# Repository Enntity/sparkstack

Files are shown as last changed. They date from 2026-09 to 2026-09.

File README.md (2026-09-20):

# SparkStack

A stackable, modular, 3D-printable rack for the NVIDIA DGX Spark. One to four
machines in a 205 mm footprint.

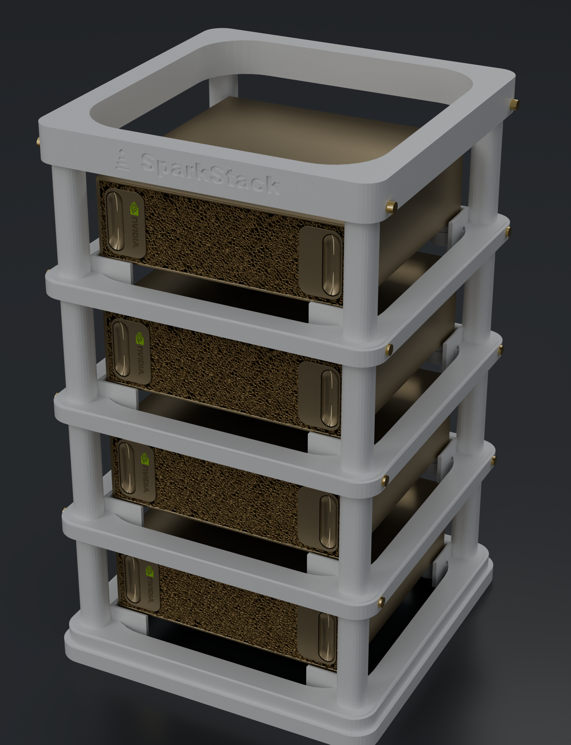
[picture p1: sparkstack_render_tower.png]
SparkStack, four machines high


Printed in ABS or ASA. Every part fits a 220 × 220 mm bed.

**Status: built and in use.** Two machines sit in a prototype on a desk, and the
assembly is fine to live with. The three structural parts are published below;
the decorative panels are not yet.

**Not affiliated with, endorsed by, or sponsored by NVIDIA.** "DGX" and "Spark"
are trademarks of NVIDIA Corporation. This is an independent accessory.

## What's here

| | |
|---|---|
| `stl/` | Ready-to-slice STLs for v3.0 |
| `sparkstack.py` | Structure generator — base, tiers, cap |
| `sparkstack_panels.py` | Decorative panel generator |
| `render_sparkstack.py` | Renders: white rack, real Sparks, gold pins |
| `render_hive.py` | Renders: dark organic finish, panels on |
| `render.sh` | Blender wrapper (see *Renders*) |
| `validate_stl.py` | Checks exports are closed, watertight, single-shell |
| `profiles/` | OrcaSlicer profiles for ASA on a FlashForge AD5M Pro |

## Print set

| File | Qty |
|---|---|
| `sparkstack_v3_0_base.stl` | 1 |
| `sparkstack_v3_0_tier.stl` | 1 per machine |
| `sparkstack_v3_0_cap.stl` | 1 |
| `sparkstack_v3_0_tier_pinned.stl` | optional — the tier with the pin bore opened through the rail. **See The joint** |

**Three parts.** A four-machine stack is one base, four tiers, one cap. The
`tier_pinned` file is the same tier with one bore opened up; print it instead of
`tier` if you want to use pins.

The **decorative panels are not in this release.** The generator is here and the
renders below show them fitted, but the panel STLs are not published yet — see
*Panels* for how they work and why they need a little more time.

## Model

1 unit = 1 mm. Everything is generated, not hand-modelled:

```bash
blender --background --python sparkstack.py    # writes stl/ and a spec sheet
```

Key parameters live in the `P` dict at the top of `sparkstack.py`:

| | | |
|---|---|---|
| `PITCH` | 76 mm | tier spacing; sets the air gap above each machine |
| `DEV_W` / `DEV_D` / `DEV_H` | 150 / 150 / 51.2 | the machine |
| `SIDE_CLEAR` | 1.5 mm | post clearance |
| `JOINT_CLR` | 0.15 mm | bore clearance; the ribs interfere by 0.10 mm/side |
| `RAIL_PROUD` | 2.0 mm | panel rail standoff |
| `CRADLE_CLR` | 1.0 mm | corner cradle clearance, sized for ASA shrinkage |
| `BASE_R` | 14 mm | base corner radius |

## The constraint that shapes everything

The machine draws air in through its **front face** (upper and lower) and its
**underside**, both dust-filtered, and exhausts out the **rear** heatsink fins
and the QSFP fin stack.
([ChargerLAB teardown](https://www.chargerlab.com/teardown-of-nvidia-dgx-spark-4tb/))

So there is no shelf under it. The tier ring opens to **168 × 168 mm**, wider
than the machine's own 150 mm silhouette, leaving a 9 mm annulus around the
chassis. The machine rests on **four Ø14 mm pads** at (±68, ±68) mm, shadowing
**3.5% of the underside**, all at the corners.

That is also why the panels are **open webbing rather than solid skins** — a
closed front panel would strangle the intake.

`PITCH` sets the air gap above each machine: at 76 mm it is **11.8 mm**. For
scale, buoyancy across a full four-tier stack is ~0.26 Pa against tens of Pa
from the machine's own blowers, and the intake annulus costs ~0.13–0.25 Pa at a
plausible 10–20 CFM. The rack's contribution to the intake path is small, and
the gap above the machine is not in that path at all: the top of the chassis is
neither intake nor exhaust.

**The mechanical design is built and in use.** Two machines sit in a prototype
on a desk — they locate in the cradles, the tiers stack and hold, and the
assembly has been fine to live with.

**The numbers on this page are not the reason for that.** Every figure above is
analysis from published specs and first principles — buoyancy, annulus pressure
drop, the rising gap. No temperature logging has been done under sustained
load, and the machine dimension used throughout is the published spec, not a
measurement of the unit on the desk. Take the numbers as the reasoning behind
the shape, not as verification of it.

## Panels

**Not shipped yet.** The renders at the top of this README show them fitted;
the STLs are not in this release. Everything below describes the design as
built, so the generator in `sparkstack_panels.py` and the geometry it produces
match what you see — but treat the panel files as unreleased until they appear
in `stl/`.

Each tier's front comes from its own seed, so a stack doesn't read as four
copies of one part. The sides are identical across tiers.

The panels are flat 4 mm plates with a hook along the bottom of the inner face
that drops over a rail on the tier. Printed flat, the panel's inner face is up,
so the hook is a step in the top surface — there is no overhang anywhere, which
matters because ABS and ASA with near-zero part cooling will string and stay
uncured on any unsupported ceiling.

An earlier attempt put the locating groove in the tier's vertical wall instead.
That groove's ceiling was a flat bridge and it printed badly. Hence the rail.

## Corner cradles

Each pad is backed by a square L-shaped wall, 2.5 mm thick, rising 6 mm above
the seat. It stops the machine sliding in either axis. The plan is square on
purpose — it matches the footprint it fits — with a 1 mm round-over on the top
edge only, so no 90° edge shows in the front view. No snap lip: it was a 0.6 mm
ledge hanging over open air, exactly the overhang that strings in ASA.

`CRADLE_CLR` is 1.0 mm rather than a tight 0.25 mm because ASA shrinks ~0.6%:
over a 150 mm opening that is 0.45 mm per side, so a 0.25 mm gap would print as
an interference fit.

## The joint

Tiers join on four corner tenons into four sockets. The fit is meant to hold a
stack up on its own — the pins are insurance, not structure.

Bore **11.30 mm**, ribbed tenon **11.50 mm**: 0.10 mm of interference per side
across four crush ribs over a 7 mm band. Both halves are the same material, so
shrinkage moves them together and the fit is unchanged after printing.

**Check the fit before you commit to a full tier.** `sparkstack.py` can generate
a one-corner coupon — a half-height column carrying both halves of the joint —
which is far cheaper to print than a tier. Print two and stack them.

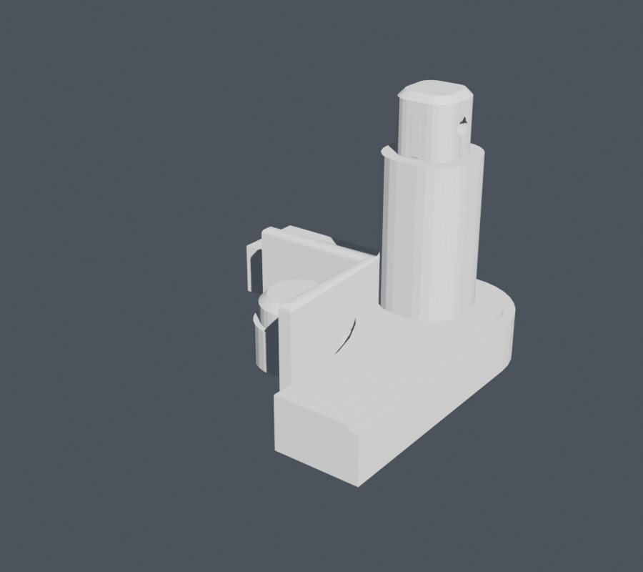
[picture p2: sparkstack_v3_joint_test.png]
Joint test coupon


If it comes out wrong, `JOINT_CLR` and `RIB` are the two numbers to move.

Gold pins through each joint are optional.

### Which tier to print

There are two, and the difference is one bore.

The pin runs along X through a post, and at the joint it has to pass through
three things: the tier's socket wall, the ring, **and the panel rail**. The rail
is unioned on *after* the socket is bored, and it is solid across |x| 98–100 at
z 3–9 — exactly where the pin exits. So on `tier.stl` the rail caps the hole:
the tenon above has a clean bore, the socket below looks drilled, and a pin will
not go in.

`tier_pinned.stl` cuts that bore once, after the rail. Verified: a clean 3.4 mm
opening at z 4.0–7.0, identical to `tier.stl` everywhere else, same 200 × 200
footprint, same rail.

The base and the cap have no rail, so their bores were never capped and they are
fine as they are.

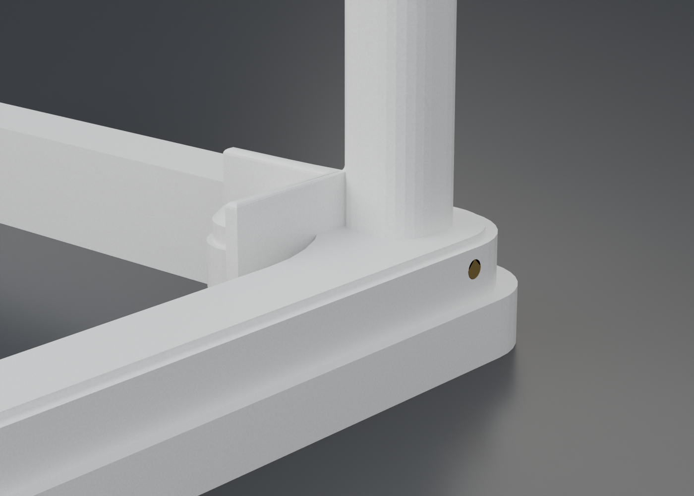
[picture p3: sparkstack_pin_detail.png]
Flush pin in the rail face


**Pins must be flush.** With the rail fitted there is no room for a head — it
would sit inside the rail. And a flush pin has nothing to grab: its inner end is
buried in the post, so you cannot push it out from the far side either. Use an
**M3 screw**, which the Ø3.4 bore already clears, or leave a small recess at the
outer end to pick at.

## Renders

| | |
|---|---|
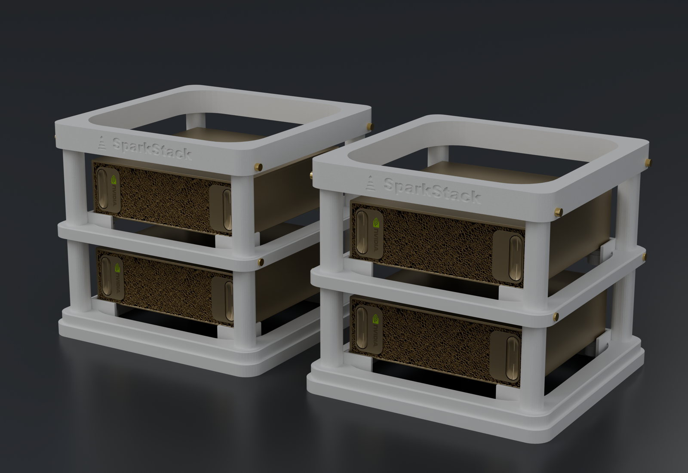
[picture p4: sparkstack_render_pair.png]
|  |  |
| Four high | Two stacks of two |
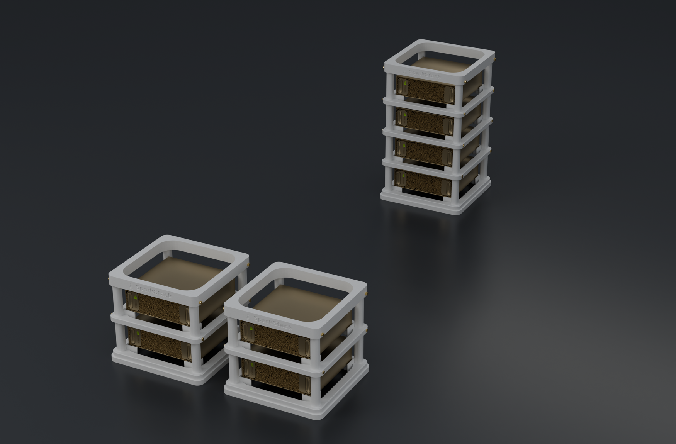
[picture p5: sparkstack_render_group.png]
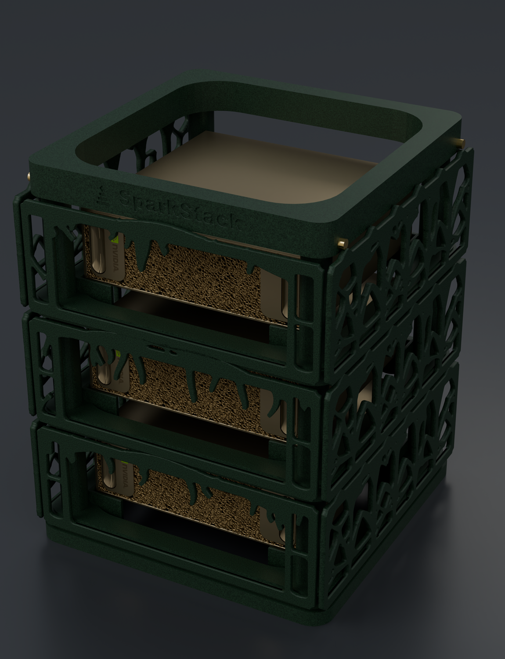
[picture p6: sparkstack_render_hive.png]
|  |  |
| Two stacks and a tower | Dark organic finish — **panels fitted, not shipped** |
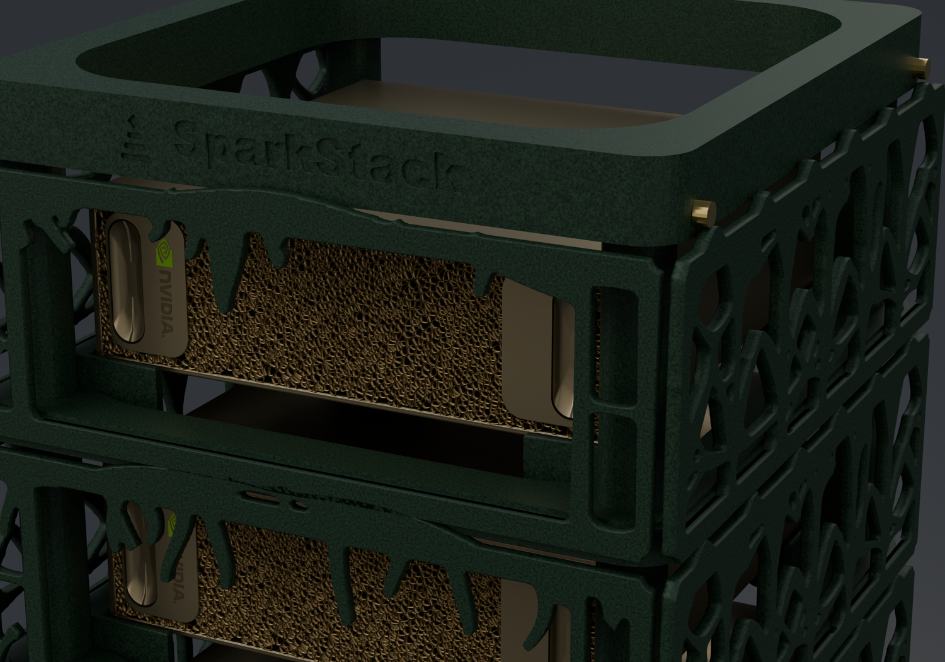
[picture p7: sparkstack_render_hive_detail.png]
|  | |
| Honeycomb webbing, drips, wordmark, gold pins | |

`render_sparkstack.py` and `render_hive.py` drive Cycles from a script — no
HDRI, no image textures, no manual scene setup. Use the wrapper:

```bash
./render.sh --background --python render_hive.py
```

The wrapper exists because Cycles compiles its Metal kernels on the first GPU
render of a session and caches them under `$HOME/Library/Caches`. Under a
sandboxed or read-only home that path is unwritable, the compile repeats on
every launch, and you pay 150–200 s per run instead of ~10 s. `render.sh` points
`HOME` at a local directory so the cache persists. Harmless outside a sandbox.

On an M2 Max at 1150 × 1500, 32 samples:

| | |
|---|---|
| CPU | 31.7 s per frame |
| GPU, first of a session | 152–208 s (kernel compile) |
| GPU, warm | **3.2 s per frame** |

`cycles.preferences.devices` is **lazily enumerated** — it stays empty until you
call `get_devices()`, so setting `cycles.device = 'GPU'` on its own enables
nothing and Cycles falls back to CPU without raising. Both scripts do it
properly; if you copy the setup, don't drop that call.

**The Spark model is not included.** It is a third-party asset and not ours to
redistribute. The render scripts will tell you where to download it (free, no
signup); the rack itself needs none of it. Those renders are visualisations
against an unofficial model, not NVIDIA CAD — don't take connector clearances
off them.

## Printing

ABS or ASA. Enforced, not a preference: the design leans on those materials'
stiffness and temperature resistance.

Slicer profiles for both, for the FlashForge AD5M Pro with a 0.4 nozzle, in
`profiles/` — a process profile and a filament profile for each. Import them
together; the process profile is material-independent apart from a little extra
warping margin.

| | ASA | ABS |
|---|---|---|
| Nozzle | 255 °C | 250 °C |
| Nozzle, first layer | 255 °C | 255 °C |
| Bed | 105 °C | 105 °C |
| Fan | 10–15% | 10–15% |
| Brim | 6 mm | **8 mm** |
| First layer speed | 35 mm/s | **30 mm/s** |
| Outer wall | 120 mm/s | **100 mm/s** |

Everything else is shared, including the near-zero cooling. ABS is the more
warp-prone of the two, hence the wider brim and slower first layer — the
**base at 205 mm** is the part that will lift if anything does.

Close the enclosure and keep the room still. ABS puts out styrene while it
prints, so ventilate the room, not the printer. Textured PEI at 105 °C, and let
the bed cool before removing parts or you will pull the bottom face off with
them.

- Bed contact ranges 4,163–13,820 mm² across the parts
- Overhang ≤ 2.1% on every part; there are no intentional unsupported spans
- Print the panels flat — thickness is the build direction, and local z = 0 is
  the outer face (bed side)
- Every exported STL is verified closed, watertight, and **single-shell**;
  `python3 validate_stl.py stl/*.stl` re-checks it

## License

**CC BY-NC-SA 4.0** — see `LICENSE`.

You may download, modify, and print these files for personal use, and share your
modifications under the same license. You may **not** sell prints, sell the
files, or ship them inside a commercial product.

**Commercial licensing is available.** If you want to sell printed units or a
kit, get in touch — that's a conversation, not a no.

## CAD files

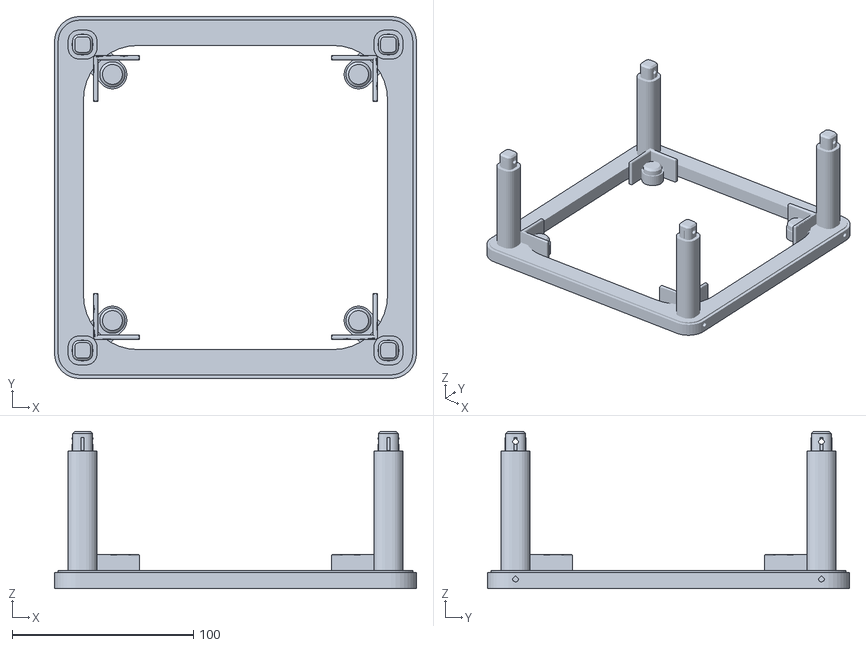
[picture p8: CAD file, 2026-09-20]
stl/sparkstack_v3_0_tier_pinned.stl
200.0 x 200.0 x 87.0

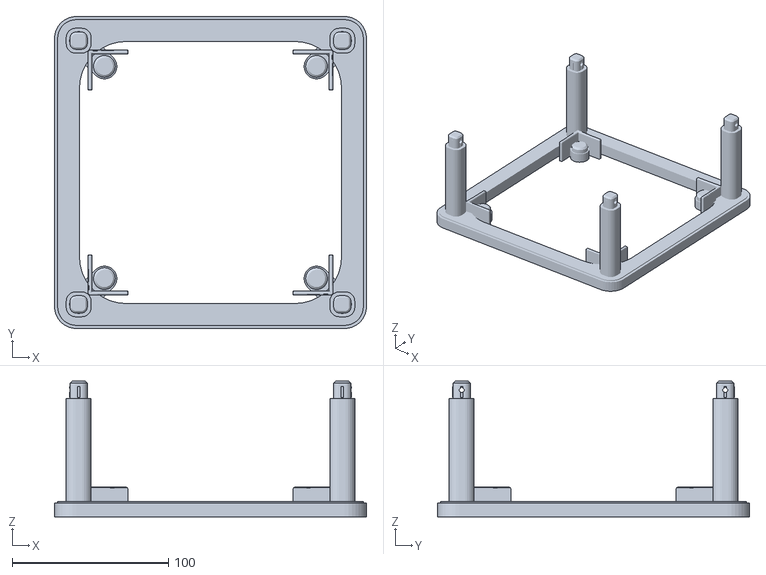
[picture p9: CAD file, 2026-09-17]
stl/sparkstack_v3_0_tier.stl
200.0 x 200.0 x 87.0

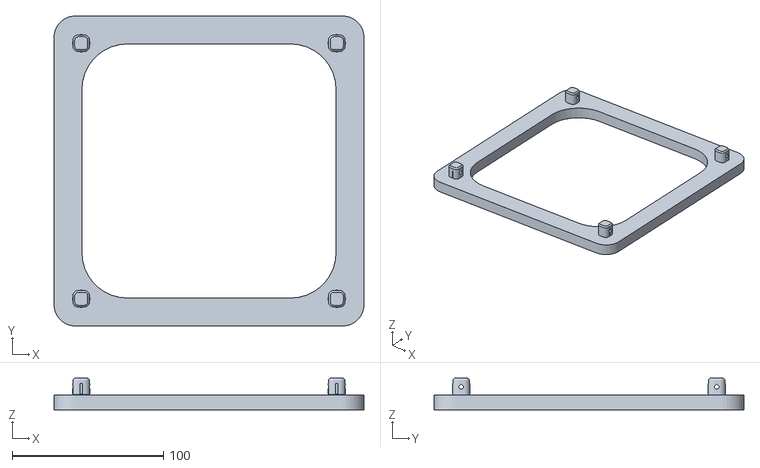
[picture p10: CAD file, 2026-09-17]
stl/sparkstack_v3_0_base.stl
205.0 x 205.0 x 21.0

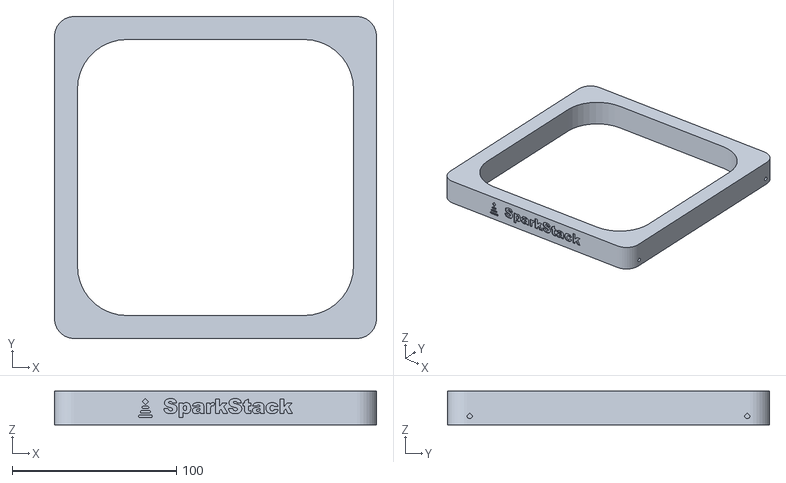
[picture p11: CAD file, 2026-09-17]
stl/sparkstack_v3_0_cap.stl
196.0 x 196.0 x 20.4

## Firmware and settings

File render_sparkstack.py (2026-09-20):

"""Render the SparkStack: white-ABS prints, photoreal Sparks.

Run headless:
    Blender --background --python render_sparkstack.py

Cycles, because the point is real reflections on the anodised chassis and soft
contact shadows under the prints. Everything is procedural - no HDRI or image
textures to ship - so the script is self-contained and repeatable.

Note on scale: 1 unit = 1 mm. Light positions land around 1000-2000 units, i.e.
1-2 m, so wattages are in the usual range rather than megawatts.
"""
import bpy
import math
import os
import sys
from mathutils import Matrix, Vector

sys.path.insert(0, os.path.dirname(os.path.abspath(__file__)))
import sparkstack as SS                                   # noqa: E402

HERE = os.path.dirname(os.path.abspath(__file__))
DEV_W = DEV_D = 150.0
DEV_H = 51.2
DEV_R = 18.0
GOLD_LO, GOLD_HI = 4.0, 47.0
# Two intake bands, not one big recess: the teardown shows the front
# face drawing air through an upper AND a lower grille, with the
# chassis between them. One 42 mm recess covered 86% of the face and
# made the whole front read black.
GRILLE_W, GRILLE_T, GRILLE_D = 126.0, 9.0, 2.2
GRILLE_Z = (13.0, 33.0)


# --------------------------------------------------------------------------- #
# scene plumbing
# --------------------------------------------------------------------------- #
def reset():
    for coll in list(bpy.data.collections):
        bpy.data.collections.remove(coll)
    for ob in list(bpy.data.objects):
        bpy.data.objects.remove(ob, do_unlink=True)
    for coll in (bpy.data.meshes, bpy.data.materials, bpy.data.lights,
                 bpy.data.cameras, bpy.data.node_groups):
        for block in list(coll):
            if block.users == 0:
                coll.remove(block)


def node(nt, kind, **kw):
    n = nt.nodes.new(kind)
    for k, v in kw.items():
        setattr(n, k, v)
    return n


def set_in(n, key, value):
    if key in n.inputs:
        n.inputs[key].default_value = value
    return n


# --------------------------------------------------------------------------- #
# materials
# --------------------------------------------------------------------------- #
def mat_white_abs():
    """White ABS. Off pure white, because pure white reads as CG."""
    m = bpy.data.materials.new("white_abs")
    m.use_nodes = True
    nt = m.node_tree
    nt.nodes.clear()
    out = node(nt, 'ShaderNodeOutputMaterial')
    bsdf = node(nt, 'ShaderNodeBsdfPrincipled')
    tex = node(nt, 'ShaderNodeTexCoord')
    broad = node(nt, 'ShaderNodeTexNoise', noise_dimensions='3D')
    set_in(broad, "Scale", 3.2); set_in(broad, "Detail", 4.0)
    set_in(broad, "Roughness", 0.55)
    ramp = node(nt, 'ShaderNodeValToRGB')
    ramp.color_ramp.elements[0].position = 0.35
    ramp.color_ramp.elements[0].color = (0.840, 0.840, 0.825, 1)
    ramp.color_ramp.elements[1].position = 0.68
    ramp.color_ramp.elements[1].color = (0.918, 0.918, 0.905, 1)
    rgh = node(nt, 'ShaderNodeMapRange')
    set_in(rgh, "To Min", 0.33); set_in(rgh, "To Max", 0.49)
    wav = node(nt, 'ShaderNodeTexWave', wave_type='BANDS', bands_direction='Z')
    set_in(wav, "Scale", 0.5); set_in(wav, "Distortion", 0.4)
    bump = node(nt, 'ShaderNodeBump')
    set_in(bump, "Strength", 0.10); set_in(bump, "Distance", 0.02)
    L = nt.links.new
    L(tex.outputs["Object"], broad.inputs["Vector"])
    L(tex.outputs["Object"], wav.inputs["Vector"])
    L(broad.outputs["Fac"], ramp.inputs["Fac"])
    L(broad.outputs["Fac"], rgh.inputs["Value"])
    L(ramp.outputs["Color"], bsdf.inputs["Base Color"])
    L(rgh.outputs["Result"], bsdf.inputs["Roughness"])
    L(wav.outputs["Fac"], bump.inputs["Height"])
    L(bump.outputs["Normal"], bsdf.inputs["Normal"])
    for k, v in (("IOR", 1.46), ("Specular IOR Level", 0.5),
                 ("Coat Weight", 0.05), ("Coat Roughness", 0.32)):
        set_in(bsdf, k, v)
    L(bsdf.outputs["BSDF"], out.inputs["Surface"])
    return m


def _metal(name, colour, rough, aniso, scale, brush=0.10, metallic=0.9):
    m = bpy.data.materials.new(name)
    m.use_nodes = True
    nt = m.node_tree
    nt.nodes.clear()
    out = node(nt, 'ShaderNodeOutputMaterial')
    bsdf = node(nt, 'ShaderNodeBsdfPrincipled')
    tex = node(nt, 'ShaderNodeTexCoord')
    noise = node(nt, 'ShaderNodeTexNoise', noise_dimensions='3D')
    set_in(noise, "Scale", scale); set_in(noise, "Detail", 2.0)
    mr = node(nt, 'ShaderNodeMapRange')
    set_in(mr, "To Min", max(0.03, rough - brush))
    set_in(mr, "To Max", rough + brush)
    bump = node(nt, 'ShaderNodeBump')
    set_in(bump, "Strength", 0.05); set_in(bump, "Distance", 0.004)
    set_in(bsdf, "Base Color", (*colour, 1.0))
    # Not 1.0. A pure metal has no diffuse term at all, so inside a shaded bay
    # with nothing bright to reflect it renders as a black hole - which is
    # exactly what the first pass looked like.
    set_in(bsdf, "Metallic", metallic)
    set_in(bsdf, "Anisotropic", aniso)
    L = nt.links.new
    L(tex.outputs["Object"], noise.inputs["Vector"])
    L(noise.outputs["Fac"], mr.inputs["Value"])
    L(mr.outputs["Result"], bsdf.inputs["Roughness"])
    L(noise.outputs["Fac"], bump.inputs["Height"])
    L(bump.outputs["Normal"], bsdf.inputs["Normal"])
    L(bsdf.outputs["BSDF"], out.inputs["Surface"])
    return m


def mat_pin_gold():
    """The joint pins. Polished, and deliberately the brightest thing on the
    rack - they are the one part that is not printed, so they should read as
    hardware."""
    return _metal("pin_gold", (0.860, 0.660, 0.285), 0.16, 0.30, 60.0, 0.04,
                  metallic=0.97)


def mat_grille():
    """Front intake as fine horizontal slats, driven by a texture.

    Modelling 40 slats would cost more triangles than the whole rack, and at
    any sane render size the wave reads identically.
    """
    m = bpy.data.materials.new("spark_grille")
    m.use_nodes = True
    nt = m.node_tree
    nt.nodes.clear()
    out = node(nt, 'ShaderNodeOutputMaterial')
    bsdf = node(nt, 'ShaderNodeBsdfPrincipled')
    tex = node(nt, 'ShaderNodeTexCoord')
    wav = node(nt, 'ShaderNodeTexWave', wave_type='BANDS', bands_direction='Z')
    set_in(wav, "Scale", 30.0); set_in(wav, "Distortion", 0.0)
    ramp = node(nt, 'ShaderNodeValToRGB')
    ramp.color_ramp.elements[0].position = 0.30
    ramp.color_ramp.elements[0].color = (0.006, 0.006, 0.008, 1)
    ramp.color_ramp.elements[1].position = 0.62
    ramp.color_ramp.elements[1].color = (0.070, 0.066, 0.060, 1)
    bump = node(nt, 'ShaderNodeBump')
    set_in(bump, "Strength", 0.9); set_in(bump, "Distance", 0.012)
    set_in(bsdf, "Metallic", 0.85)
    set_in(bsdf, "Roughness", 0.42)
    L = nt.links.new
    L(tex.outputs["Object"], wav.inputs["Vector"])
    L(wav.outputs["Fac"], ramp.inputs["Fac"])
    L(wav.outputs["Fac"], bump.inputs["Height"])
    L(ramp.outputs["Color"], bsdf.inputs["Base Color"])
    L(bump.outputs["Normal"], bsdf.inputs["Normal"])
    L(bsdf.outputs["BSDF"], out.inputs["Surface"])
    return m


def mat_floor():
    m = bpy.data.materials.new("floor")
    m.use_nodes = True
    b = m.node_tree.nodes.get("Principled BSDF")
    set_in(b, "Base Color", (0.052, 0.055, 0.060, 1))
    set_in(b, "Roughness", 0.30)
    set_in(b, "Metallic", 0.0)
    return m


# --------------------------------------------------------------------------- #
# the Spark
# --------------------------------------------------------------------------- #
SPARK_GLB = os.path.join(HERE, "assets", "dgx-spark.glb")
_SPARK_MESH = [None]


def spark_mesh():
    """Import the DGX Spark GLB once and hand back its mesh.

    A real asset beats texturing a box: this one has the champagne shell, the
    sintered open-cell grille as ACTUAL geometry (827k triangles of it), the
    rubber feet and the rear connectors. Metres, front facing -Y, feet on z=0,
    so it scales by 1000 and drops straight onto the pads.
    """
    if _SPARK_MESH[0] is not None:
        return _SPARK_MESH[0]
    if not os.path.exists(SPARK_GLB):
        raise SystemExit(
            "\nSpark model not found at %s\n\n"
            "It is a third-party asset and is deliberately not committed here.\n"
            "Download it (free, no signup) and drop it in assets/:\n\n"
            "  mkdir -p assets\n"
            "  curl -L -o assets/dgx-spark.glb \\\n"
            "    https://wendy.dev/models/dgx-spark/nvidia-dgx-spark.glb\n\n"
            "The rack itself needs none of this - only these renders do.\n"
            % SPARK_GLB)
    before = set(bpy.data.objects)
    bpy.ops.import_scene.gltf(filepath=SPARK_GLB)
    new = [o for o in bpy.data.objects if o not in before]
    meshes = [o for o in new if o.type == 'MESH']
    if not meshes:
        raise RuntimeError("no mesh in %s" % SPARK_GLB)
    src = max(meshes, key=lambda o: len(o.data.vertices))
    me = src.data
    for o in new:
        if o.type == 'EMPTY':
            bpy.data.objects.remove(o, do_unlink=True)
    _SPARK_MESH[0] = me
    print("spark mesh: %d verts, %d materials" % (len(me.vertices), len(me.materials)))
    return me


def place_spark(coll, name, loc):
    """A LINKED duplicate - eight separate 253k-vertex meshes would be 2M verts
    of needless duplication; sharing the datablock costs nothing per copy."""
    me = spark_mesh()
    o = bpy.data.objects.new(name, me)
    coll.objects.link(o)
    o.scale = (1000.0, 1000.0, 1000.0)
    # The asset's origin sits at the TOP of the device, not the bottom: its
    # local z runs about -0.049..0.0015. Placing it at the seat height would
    # bury it a full 49 mm into the rack, so lift it by its own depth.
    drop = -min(v.co.z for v in me.vertices) * 1000.0
    o.location = (loc[0], loc[1], loc[2] + drop)
    return o


def joint_pin(coll, cx, cy, z, mat):
    """One gold pin through a post joint, head outboard."""
    sgn = 1.0 if cx > 0 else -1.0
    # FLUSH. With the rail fitted the pin exits through the rail's outer face at
    # |x| = 100, and there is no room for a head - it would sit inside the rail.
    # So the pin ends exactly at that face and is pushed out from the far side.
    face = SS.P["RING"] / 2.0 + SS.P["RAIL_PROUD"]
    body = SS.cyl_x_mesh("pin", cy, z, cx - sgn * 20.0, sgn * face, 1.6, seg=20)
    o = SS.bake_seq("jointpin", [(body, 'u')], coll)
    o.data.materials.append(mat)
    return o


def joint_pin_headed(coll, cx, cy, z, mat):
    """Headless is the shipping case; kept for panels-off renders."""
    sgn = 1.0 if cx > 0 else -1.0
    # The pin has to reach the ring's OUTER face. The ring is 10 mm tall at each
    # tier's foot and the pin sits 5.5 mm up, so a pin that stops at the post
    # (24 mm) is buried inside the ring and invisible. The drilled hole runs
    # 40 mm through post and ring both, so the pin follows it out and the head
    # lands on the ring face at RING/2.
    face = SS.P["RING"] / 2.0
    body = SS.cyl_x_mesh("pin", cy, z, cx - sgn * 16.0, sgn * face, 1.55, seg=20)
    head = SS.cyl_x_mesh("pinhead", cy, z, sgn * face, sgn * (face + 3.6),
                         3.0, seg=24)
    o = SS.bake_seq("jointpin", [(body, 'u'), (head, 'u')], coll)
    o.data.materials.append(mat)
    return o


# --------------------------------------------------------------------------- #
# a whole stack
# --------------------------------------------------------------------------- #
def build_stack_at(x, y, tiers, coll, mats, white, panels=False):
    """One SparkStack plus a real Spark per tier, then translate the lot.

    Deliberately NOT SS.build_stack(): that calls reset_scene(), which would
    delete the stacks already built. Everything goes into `coll` directly.
    The front and side plates are left OFF for these renders so the device is
    not sitting behind 30%-coverage webbing.
    """
    import importlib
    import sparkstack_panels as SP
    importlib.reload(SP)
    SS.P["PANEL_RAIL"] = True

    objs = []
    body_mats = SS.build_materials()
    objs.append(SS.build_base(coll, body_mats))
    for i in range(tiers):
        t = SS.build_tier(coll, body_mats)
        t.location = (0.0, 0.0, SS.P["BASE_T"] + i * SS.P["PITCH"])
        objs.append(t)
    cap = SS.build_cap(coll, body_mats)
    cap.location = (0.0, 0.0, SS.P["BASE_T"] + tiers * SS.P["PITCH"])
    objs.append(cap)

    if panels:
        for p in SP.build_all(coll, tiers):
            if p is not None:
                objs.append(p)

    for i in range(tiers):
        z = SS.P["BASE_T"] + i * SS.P["PITCH"] + SS.P["ARM_T"] + SS.P["PAD_H"]
        objs.append(place_spark(coll, "spark_%d" % (i + 1), (0.0, 0.0, z)))

    # gold pins: every tier joint, plus the one under the cap. The pin holes
    # for tier k and the cap both land on BASE_T + k*PITCH + PIN_Z.
    for k in range(1, tiers + 1):
        z = SS.P["BASE_T"] + k * SS.P["PITCH"] + SS.P["PIN_Z"]
        for sx in (-1, 1):
            for sy in (-1, 1):
                objs.append(joint_pin(coll, sx * SS.POST_C, sy * SS.POST_C, z,
                                      mats["pin"]))

    for o in objs:
        # NEVER SS.cleanup() an imported Spark. That merges verts within
        # `dist`, and dist is in the MESH's units - the GLB is in metres, so
        # 0.003 is a 3 mm merge against 0.09 mm foam cells. It took the model
        # from 253,526 verts to 296 and the sintered front became a handful of
        # angular shards. The rack parts are modelled in mm, so for them the
        # same number is three microns and correct.
        if o.name.startswith("spark"):
            continue
        SS.cleanup(o)
        o.data.materials.clear()
        o.data.materials.append(white if not o.name.startswith("jointpin")
                                else mats["pin"])

    bpy.context.view_layer.update()
    M = Matrix.Translation((x, y, 0.0))
    for o in objs:
        o.matrix_world = M @ o.matrix_world
    return objs


# --------------------------------------------------------------------------- #
# studio
# --------------------------------------------------------------------------- #
def area_light(name, coll, loc, target, size, power, colour=(1, 1, 1)):
    d = bpy.data.lights.new(name, type='AREA')
    d.shape = 'RECTANGLE'
    d.size, d.size_y = size[0], size[1]
    d.energy = power
    d.color = colour
    o = bpy.data.objects.new(name, d)
    coll.objects.link(o)
    o.location = loc
    o.rotation_euler = (Vector(target) - Vector(loc)).normalized() \
        .to_track_quat('-Z', 'Y').to_euler()
    return o


def setup_studio(coll, target, radius, world=0.72):
    w = bpy.data.worlds.new("studio")
    bpy.context.scene.world = w
    w.use_nodes = True
    nt = w.node_tree
    nt.nodes.clear()
    out = node(nt, 'ShaderNodeOutputWorld')
    bg = node(nt, 'ShaderNodeBackground')
    tex = node(nt, 'ShaderNodeTexCoord')
    sep = node(nt, 'ShaderNodeSeparateXYZ')
    ramp = node(nt, 'ShaderNodeValToRGB')
    ramp.color_ramp.elements[0].position = 0.32
    ramp.color_ramp.elements[0].color = (0.055, 0.058, 0.065, 1)
    ramp.color_ramp.elements[1].position = 0.72
    ramp.color_ramp.elements[1].color = (0.55, 0.58, 0.64, 1)
    set_in(bg, "Strength", world)
    L = nt.links.new
    L(tex.outputs["Generated"], sep.inputs["Vector"])
    L(sep.outputs["Z"], ramp.inputs["Fac"])
    L(ramp.outputs["Color"], bg.inputs["Color"])
    L(bg.outputs["Background"], out.inputs["Surface"])

    t = Vector(target)
    def at(*k):
        return t + Vector(k) * radius
    area_light("key", coll, at(-1.05, -1.35, 1.30), t, (900, 900), 6.0e6)
    area_light("fill", coll, at(1.45, -0.95, 0.45), t, (700, 700), 1.1e6,
               (0.85, 0.90, 1.0))
    area_light("rim", coll, at(0.25, 1.55, 0.95), t, (1400, 300), 2.0e6,
               (1.0, 0.96, 0.88))
    # A wide, low panel straight in front. Its only job is to spill through the
    # panel openings so the Sparks are lit where they sit, not just at the
    # silhouettes - the bays are otherwise a closed box.
    area_light("bay", coll, at(0.0, -1.45, 0.22), t, (2800, 900), 2.4e6,
               (1.0, 0.97, 0.93))
    # Two side fills, for the same reason: the side panels are 30% open and the
    # gold flanks are what shows through them.
    for sx in (-1, 1):
        area_light("side%d" % sx, coll, at(sx * 1.55, -0.75, 0.30), t,
                   (1500, 900), 1.5e6, (1.0, 0.98, 0.95))


def setup_render(res, samples=64, device='GPU'):
    """Configure Cycles.

    The device selection matters and is easy to get silently wrong.
    `cycles.preferences.devices` is LAZILY enumerated and stays an empty list
    until get_devices() is called, so setting cycles.device='GPU' on its own
    enables nothing and Cycles falls back to CPU without raising - which is
    exactly what happened here for several renders. Worse, it was wrapped in a
    bare try/except that would have swallowed the evidence anyway.

    Measured on this scene at 1150x1500 @32spp, M2 Max:
        CPU                     31.7 s per frame, every frame
        GPU, first of a session 152-208 s   (Metal kernel compile)
        GPU, warm                3.2 s per frame
    The compile is cached under $HOME/Library/Caches, so the first is a one-off
    - see render.sh. Warm GPU is ~10x the CPU, so GPU is the default.
    """
    sc = bpy.context.scene
    sc.render.engine = 'CYCLES'
    sc.cycles.samples = samples
    sc.cycles.use_denoising = True
    sc.cycles.max_bounces = 8
    sc.cycles.transmission_bounces = 6
    sc.cycles.use_adaptive_sampling = True
    sc.cycles.adaptive_threshold = 0.01

    cp = bpy.context.preferences.addons['cycles'].preferences
    cp.compute_device_type = 'METAL'
    cp.get_devices()                       # without this, devices stays empty
    for d in cp.devices:
        d.use = (d.type != 'CPU')
    sc.cycles.device = device
    sc.cycles.denoising_use_gpu = (device == 'GPU')
    sc.render.resolution_x, sc.render.resolution_y = res
    sc.render.resolution_percentage = 100
    sc.render.image_settings.file_format = 'PNG'
    sc.view_settings.view_transform = 'AgX'
    sc.view_settings.look = 'AgX - Medium High Contrast'
    sc.render.film_transparent = False


SS_FACTOR = 2          # supersample, then downscale outside Blender


def shoot(cam, path, loc, target, lens):
    """Render at SS_FACTOR x and hand the downscale to the caller.

    The Spark's sintered front is real geometry with ~0.09 mm cells. At rack
    framing that is a quarter of a pixel per cell, so rendering at final size
    aliases the foam into big angular shards that look nothing like the model.
    Oversampling first averages it back into grain.
    """
    sc = bpy.context.scene
    rx, ry = sc.render.resolution_x, sc.render.resolution_y
    cam.data.lens = lens
    cam.location = loc
    cam.rotation_euler = (Vector(target) - Vector(loc)).normalized() \
        .to_track_quat('-Z', 'Y').to_euler()
    sc.camera = cam
    sc.render.resolution_x, sc.render.resolution_y = rx * SS_FACTOR, ry * SS_FACTOR
    sc.render.filepath = path.replace(".png", "_ss.png")
    bpy.ops.render.render(write_still=True)
    sc.render.resolution_x, sc.render.resolution_y = rx, ry
    print("rendered", os.path.basename(path), "at", rx * SS_FACTOR, "x", ry * SS_FACTOR)


def main():
    reset()
    sc = bpy.context.scene
    coll = bpy.data.collections.new("RENDER")
    sc.collection.children.link(coll)

    mats = {"pin": mat_pin_gold()}
    white = mat_white_abs()

    fm = bpy.data.meshes.new("floor")
    fm.from_pydata([(-9000, -9000, 0), (9000, -9000, 0),
                    (9000, 9000, 0), (-9000, 9000, 0)], [], [(0, 1, 2, 3)])
    fm.update()
    floor = bpy.data.objects.new("floor", fm)
    coll.objects.link(floor)
    floor.data.materials.append(mat_floor())

    cd = bpy.data.cameras.new("cam")
    cd.clip_start = 5.0
    cd.clip_end = 60000.0
    cam = bpy.data.objects.new("cam", cd)
    coll.objects.link(cam)

    # two stacks of two, side by side
    SPACING = 250.0
    pair = []
    for k, x in enumerate((-SPACING / 2.0, SPACING / 2.0)):
        pair += build_stack_at(x, 0.0, 2, coll, mats, white)
    # one tower of four, set back so the group shot reads in depth
    tower = build_stack_at(0.0, 900.0, 4, coll, mats, white)

    def show(objs):
        """Each part gets its own shot - leaving the other stack in frame puts
        a stray rack in the corner and eats half the composition."""
        for o in pair + tower:
            o.hide_render = o not in objs

    setup_studio(coll, (0.0, 420.0, 150.0), 950.0)

    # Framing. With sensor_fit AUTO the 36 mm sensor maps to whichever render
    # dimension is LARGER, so a portrait frame is limited by its height and a
    # landscape one by its width. Distance = needed_extent * lens / 36.
    def at(target, d, metres):
        return (target[0] + d[0] * metres, target[1] + d[1] * metres,
                target[2] + d[2] * metres)

    setup_render((1600, 1100))
    show(pair)
    t = (0.0, 0.0, 95.0)
    shoot(cam, os.path.join(HERE, "sparkstack_render_pair.png"),
          at(t, (0.50, -0.82, 0.28), 1320.0), t, 85.0)

    setup_render((1150, 1500))
    show(tower)
    t = (0.0, 900.0, 168.0)
    shoot(cam, os.path.join(HERE, "sparkstack_render_tower.png"),
          at(t, (0.40, -0.79, 0.46), 1020.0), t, 85.0)

    setup_render((1750, 1150))
    show(pair + tower)
    t = (0.0, 400.0, 130.0)
    shoot(cam, os.path.join(HERE, "sparkstack_render_group.png"),
          at(t, (0.42, -0.80, 0.43), 3100.0), t, 80.0)
    print("done")


if __name__ == "__main__":
    main()

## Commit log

2026-09-17 SparkStack v3.0 - stackable printable rack for the DGX Spark
    An open frame that holds one to four machines in a 205 mm footprint, with
    clip-on decorative panels. Generated, not hand-modelled: sparkstack.py emits
    the STLs and render_*.py drives Cycles from a script with no manual setup.
    Three things drove the design:
    - The machine draws air through its front face and its underside, so the tier
    ring opens to 168x168 and only four small pads touch the chassis. The panels
    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
    [sparkstack_v3_0_base.stl, sparkstack_v3_0_cap.stl, sparkstack_v3_0_joint_test.stl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]
2026-09-17 Ship only base, tier and cap
    The panels are not ready to publish, so pull their STLs and the joint-test
    coupon out of stl/. The generators all stay, and the README still describes how
    the panels work - it just says plainly that the files are unreleased rather than
    linking to files that aren't here.
    The panel and coupon STLs are gitignored, not deleted, so they can keep being
    regenerated locally without leaking back into the repo.
    Verified the three shipped STLs byte-for-byte against the copies on the Desktop:
    all three match.
    [sparkstack_v3_0_joint_test.stl, sparkstack_v3_0_panel_front_T1.stl, sparkstack_v3_0_panel_front_T2.stl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]
2026-09-17 Use the tower render as the README hero
    It shows the three parts that actually ship, with no panels, which matches the
    release. Sized to 420px so a portrait image does not dominate the page.
    The other renders were left unreferenced by that swap, so they now sit in a
    small gallery in the Renders section, and the joint-test coupon image is next to
    the instructions for generating one.
    Also dropped "with clip-on decorative panels" from the opening line - the panels
    are not in this release, so leading with them promised something that is not
    here.
2026-09-17 Correct the verification claim: it has been built
    The README said "None of this has been measured on hardware." That was wrong -
    two machines are sitting in a prototype on a desk and the assembly works. I
    wrote it as a blanket disclaimer without asking, which is its own kind of
    inaccuracy: it understated real work.
    Split the claim rather than deleting it, because the two halves are genuinely
    different:
    - The mechanical design IS built and in use. Cradles locate, tiers stack and
    hold, and it has been fine to live with.
    - The NUMBERS on the page are still analysis, not measurement. No temperature
    logging under sustained load, and the machine dimension used throughout is
    the published s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
2026-09-17 Drop the stale hero render and fix its caption
    sparkstack_v3_hero.png was a four-high stack WITH panels, captioned as "Single
    tier, showing the rail and cradles". The file predates the current design, so
    the caption had drifted away from what the image actually shows - exactly the
    kind of thing a reader notices and then distrusts the rest of the page over.
    Deleted rather than recaptioned: a four-high shot with panels is already
    covered by two other images in the gallery, and the panel-fitted look is shown
    by the hive renders.
    Checked the remaining captions against the images themselves rather than
    assuming. The joint-test coupon image is genuinely the corner coupon.
2026-09-17 Make the source actually reproduce the shipped STLs
    Two problems found by regenerating and diffing against what was committed.
    1. PANEL_GROOVE defaulted to False, so `blender --background --python
    sparkstack.py` produced a tier WITHOUT the rail: 196 mm across against the
    shipped 200 mm. The published source generated a different part from the
    published STL. It is now PANEL_RAIL, default True, renamed because the
    feature moved off the tier's wall and onto its foot - it is a rail, not a
    groove. Renders updated to match.
    Verified after the fix: base, tier and cap regenerate byte-identical to the
    committed files.
    2. The README said sparkstack.py can generate the joint-tes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
    [render_sparkstack.py]
2026-09-20 Add ABS slicer profiles for the AD5M Pro
    Same pair as the ASA ones - a process profile and a filament profile - for
    FlashForge Studio. Derived from the validated ASA profiles rather than written
    fresh, so only material-specific values move: 57 of 59 filament settings are
    identical, and the process profile changes only warping margin.
    ASA -> ABS:
    nozzle 255 -> 250 C (first layer stays 255)
    nozzle range 245-270 -> 240-265
    fan, first layers 2 -> 3
    brim width 6 -> 8 mm
    first layer speed 35 -> 30 mm/s
    outer wall 120 -> 100 mm/s
    ABS warps harder than ASA, so the brim and the slow first layer are insurance
    for the 205 mm base - the part most likely to l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
    [sparkstack_v3_0_tier_pinned.stl]
2026-09-20 Pull the pinned tier back out of the published tree
    It should not have gone up. The previous commit was meant to add ABS profiles,
    but `git add -A` swept in the pinned-tier STL, its render, and the two source
    files from that work - none of which had been approved for release. I had
    explicitly said the pinned variant was local only, so publishing it contradicted
    that.
    Removing the two release artifacts and gitignoring them. The source changes
    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
    [sparkstack_v3_0_tier_pinned.stl]
2026-09-20 Publish the pin-through-rail tier
    Reverses the previous revert. The variant is approved, so it goes up properly
    this time - with documentation rather than as a stray file swept in by git
    add -A.
    The README now explains which of the two tiers to print and why they differ:
    the panel rail is unioned on after the socket is bored and is solid exactly
    where the pin exits, so it caps the hole. tier_pinned.stl cuts that bore once,
    after the rail.
    Also documents that pins have to be flush - there is no room for a head inside
    the rail - and that a flush pin cannot be pushed out from the far side, so it
    wants to be an M3 screw.
2026-09-20 Add the pinned tier and its detail render
    git rm without --cached deleted both from disk as well as the index, so the
    previous commit published a README linking two files that no longer existed.
    Regenerated both: the tier from sparkstack.py with PIN_THROUGH_RAIL on, the
    render from the flush-pin scene.
    [sparkstack_v3_0_tier_pinned.stl]
